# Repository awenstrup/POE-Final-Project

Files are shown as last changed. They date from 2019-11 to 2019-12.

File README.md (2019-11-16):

# POE-Final-Project

### Minimum Viable Product
Our MVP is to a build an intelligent, battery powered four wheel vehicle with remote data acquisition capabilities and sensor informed driving characteristics. Some stretch goals of ours are to include an intelligent drive algorithm with variable torque delivery for our wheels, self driving capabilities, aerodynamic features, video recording ability, and real time data plotting. We aim to prioritize robust, informed design and reliability. 

This project is a work in progress, with an estimated completion date in early December. Stay tuned for more updates.

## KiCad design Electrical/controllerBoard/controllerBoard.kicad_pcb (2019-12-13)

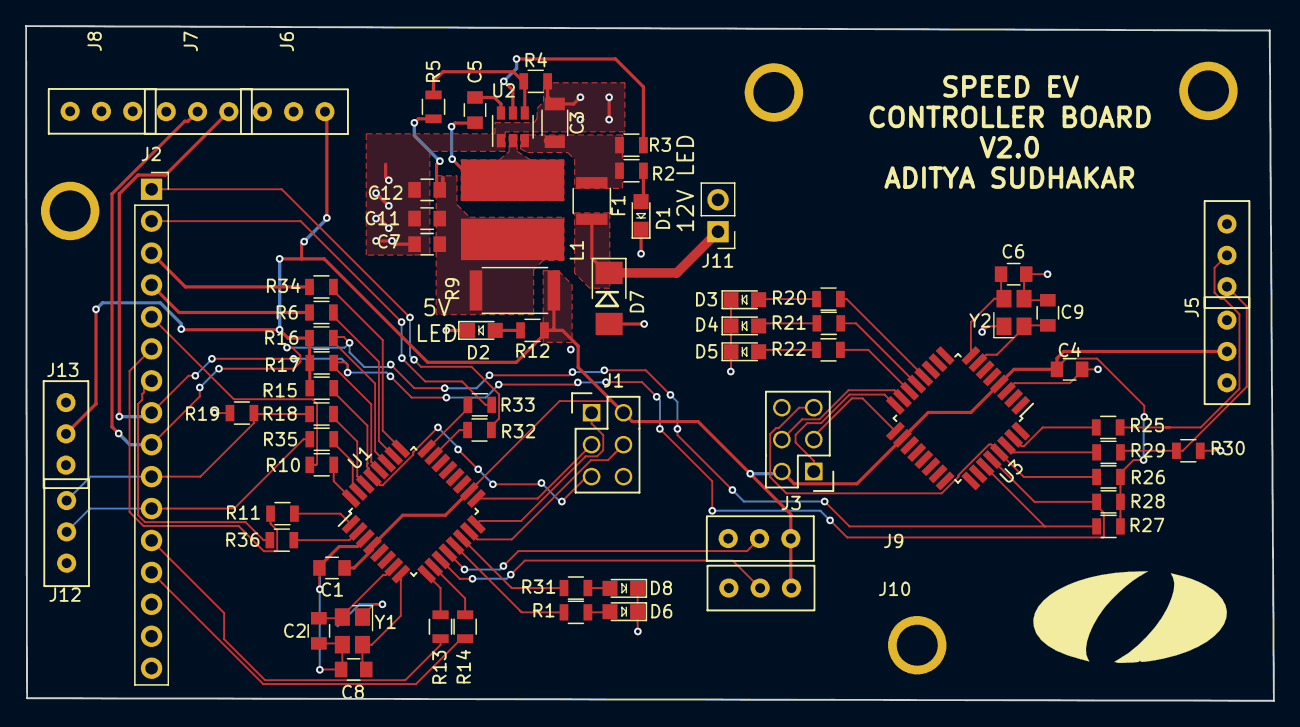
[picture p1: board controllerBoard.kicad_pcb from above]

Board: 2 copper layers, 99.3 x 53.7 mm, 71 parts (0 on the bottom side), 63 nets.

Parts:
C1, C4, C5, C12: C_0.1uF; C_0805_OEM
C2, C6, C8, C9: C_30pF; C_0805_OEM
C3: C_22uF; C_1206_OEM
C7: C_47uF; C_0805_OEM
C11: C_1uF; C_0805_OEM
D1, D2, D3, D4, D5, D6, D8: LED_0805; LED_0805_OEM
D7: D_Zener_18V; DO-214AA
F1: 500mA; Fuse_1210
J1, J3: CONN_02X03; Pin_Header_Straight_2x03
J2: 0.1in_Female_Socket_01x16; PinSocket_1x16_P2.54mm_Vertical
J4, J5, J6, J7, J8, J9, J10, J12, J13: CONN_01X03; MHSS1105
J11: CONN_01x02; PinHeader_1x02_P2.54mm_Vertical
L1: L_4.7uH; 4.7uH_Inductor_OEM
R1, R12, R20, R21, R22, R31: R_200; R_0805_OEM
R2: R_1k; R_0805_OEM
R3, R4: R_10k; R_0805_OEM
R5: R_51.1k; R_0805_OEM
R6, R10, R11, R13, R14, R25, R32, R33, R34, R35, R36: R_0; R_0805_OEM
R9: R_0_Jumper; R_2512_OEM
R15, R16, R17, R26, R27, R28: R_10K; R_0805_OEM
R18, R29: R_1K; R_0805_OEM
R19, R30: R_2.2K; R_0805_OEM
U1, U3: ATmega328P-AU; TQFP-32_7x7mm_P0.8mm
U2: TPS561201; SOT-23-6_OEM
Y1, Y2: Crystal_SMD; Crystal_SMD_FA238

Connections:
+9V: D7.1, F1.1, J11.1
/12V_Fused: C3.1, F1.2, R2.1, R3.1, U2.3
/IO1: J2.1, R32.1
/IO2: J2.2, R33.1
/IO3: J2.3, R34.1
/IO4: J2.4, R6.1
/IO5: J2.5, R10.1
/IO6: J2.6, R11.1
/IO7: J2.7, R36.1
/IO8: J2.12, R13.1
/IO9: J2.13, R14.1
/MISO: J1.1, U1.16
/MISO2: J3.1, U3.16
/MOSI: J1.4, U1.15
/MOSI2: J3.4, U3.15
/RESET: J1.5, R15.2, U1.29
/RESET2: J3.5, R26.2, U3.29
/RX: J2.10, J12.3, R18.1, R19.2
/RX2: J4.3, R29.1, R30.2
/SCK: J1.3, U1.17
/SCK2: J3.3, U3.17
/SCL: J2.8, J7.1, R17.2, R28.2, U1.28, U3.28
/SDA: J2.9, J7.2, R16.2, R27.2, U1.27, U3.27
/STEERING_SENSE: J10.2, U1.11
/THROTTLE_SENSE: J9.2, U1.12
/TX: J2.11, J12.2, R35.1
/TX2: J4.2, R25.1
/XTAL1: C2.1, U1.7, Y1.1
/XTAL2: C8.1, U1.8, Y1.3
/XTAL3: C9.1, U3.7, Y2.1
/XTAL4: C6.1, U3.8, Y2.3
GND: C1.2, C2.2, C3.2, C4.2, C6.2, C7.2, C8.2, C9.2, C11.2, C12.2, D1.1, D2.1, D3.1, D4.1, D5.1, D6.1, D7.2, D8.1, J1.6, J3.6, J5.1, J6.3, J9.3, J10.3, J11.2, J13.1, R4.2, R19.1, R30.1, U1.3, U2.1, U3.3, Y1.2, Y1.4, Y2.2, Y2.4
unnamed: C5.1, U2.6
unnamed: C5.2, L1.1, U2.2
unnamed: C7.1, C11.1, C12.1, L1.2, R5.2, R9.2
unnamed: D1.2, R2.2
unnamed: D2.2, R12.2
unnamed: D3.2, R20.1
unnamed: D4.2, R21.1
unnamed: D5.2, R22.1
unnamed: D6.2, R1.1
unnamed: D8.2, R31.1
unnamed: R1.2, U1.13
unnamed: R3.2, U2.5
unnamed: R4.1, R5.1, U2.4
unnamed: R6.2, U1.26
unnamed: R10.2, U1.32
unnamed: R11.2, U1.1
unnamed: R13.2, U1.9
unnamed: R14.2, U1.10
unnamed: R18.2, U1.30
unnamed: R20.2, U3.12
unnamed: R21.2, U3.13
unnamed: R22.2, U3.14
unnamed: R25.2, U3.31
unnamed: R29.2, U3.30
unnamed: R31.2, U1.14
unnamed: R32.2, U1.23
unnamed: R33.2, U1.24
unnamed: R34.2, U1.25
unnamed: R35.2, U1.31
unnamed: R36.2, U1.2
VCC: C1.1, C4.1, J1.2, J3.2, J5.2, J6.1, J9.1, J10.1, J13.2, R9.1, R12.1, R15.1, R16.1, R17.1, R26.1, R27.1, R28.1, U1.4, U1.18, U3.4, U3.18

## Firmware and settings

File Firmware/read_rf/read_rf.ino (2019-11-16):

//***********Include libraries***************
#include <Wire.h>
#include <Adafruit_MotorShield.h>
#include "utility/Adafruit_MS_PWMServoDriver.h"
#include <Servo.h>

//*************Define constants and global variables***************
#define throttlePin 5 //column 2 on reciever side; left stick up/down
#define steeringPin 6 //column 0 on reciever; right stick left/right

//Min and max pulse lengths from reciever, used for mapping
#define rawThrottleMin 1054
#define rawThrottleMax 1888
#define rawThrottleDeadZone 80

#define rawSteeringMin 1052
#define rawSteeringMax 1886

//Min and max values to write to DC motors through motor shield
#define throttleOutMin -255
#define throttleOutMax 255

//Min and max values to write to steering servo through motor shield
#define steeringOutMin 50
#define steeringOutMax 110

unsigned long timer = 0;
boolean go = false;

unsigned long rawThrottle = 0;
unsigned long rawSteering = 0;

//Stores the current state of the throttle and steering pins
boolean throtPinState = false;
boolean steerPinState = false;

//Set to true when a pin's state is changed
boolean throttleUpdate = false;
boolean steeringUpdate = false;

//Stores the time at which the pin went high
unsigned long steerStartTime;
unsigned long throtStartTime;

int throttleOut = 0;
int steeringOut = 80;

Adafruit_MotorShield AFMS = Adafruit_MotorShield(); 
Adafruit_DCMotor *drivingMotor1 = AFMS.getMotor(1); //motor 1 on shield
Adafruit_DCMotor *drivingMotor2 = AFMS.getMotor(2); //motor 2 on shield


Servo steering;
#define steeringServoPin 9

//************Setup*****************
void initTimer() { //addapted from https://www.instructables.com/id/Arduino-Timer-Interrupts/
  TCCR2A = 0;// set entire TCCR2A register to 0
  OCR2A = 255;// matches every 255 times
  // turn on CTC mode
  TCCR2A |= (1 << WGM21);
  // Set CS21 bit for 1024 prescaler
  TCCR2B |= 0b00000111;   
  // enable timer compare interrupt
  TIMSK2 |= (1 << OCIE2A);
}

void initPCINT() {
  //Enables interupts on shutdown sense pins
  PCICR |= 0b00000100; //enables PCINTs 16-23 
  PCMSK2 |= 0b01100000; //enables PCINT21 and PCINT22
}


//*************Interupts*************
ISR(TIMER2_COMPA_vect) {
    //count 800,000 times/second
    timer++;
    if (timer % 20 == 0) go = true;
}

ISR(PCINT2_vect) {
  boolean t1 = digitalRead(throttlePin);
  boolean t2 = digitalRead(steeringPin);
  throttleUpdate = (throtPinState != t1);
  steeringUpdate = (steerPinState != t2);
  throtPinState = t1;
  steerPinState = t2;
  digitalWrite(13, !digitalRead(13));
}



//************Helper functions******************
void readThrottle() { 
  //rudimentary implimentation used pulseIn arduino function
  //in future, either feed PWM though RC filter and analogRead, or use interupts
  //to read PWM more efficiently
  //rawThrottle = pulseIn(throttlePin, HIGH);

  if (throttleUpdate) {
    if (throtPinState) {
      throtStartTime = timer;
    }
    else {
      rawThrottle = timer - throtStartTime;
    }
    throttleUpdate = false;
  }
}

void readSteering() {
  //rudimentary implimentation used pulseIn arduino function
  //in future, either feed PWM though RC filter and analogRead, or use interupts
  //to read PWM more efficiently
  //rawSteering = pulseIn(steeringPin, HIGH);

  if (steeringUpdate) {
    if (steerPinState) {
      steerStartTime = timer;
    }
    else {
      rawSteering = timer - steerStartTime;
    }
    steeringUpdate = false;
  }
}

void mapThrottle() { //Converts raw throttle data to output
  //For week 1, return in range 0 to 255
  int rawThrottleMidpoint = (rawThrottleMax + rawThrottleMin) / 2;

  if (abs(rawThrottle - rawThrottleMidpoint) < rawThrottleDeadZone) rawThrottle = rawThrottleMidpoint;
  else if (rawThrottle < rawThrottleMin) rawThrottle = rawThrottleMin;
  else if (rawThrottle > rawThrottleMax) rawThrottle = rawThrottleMax;

  throttleOut = throttleOutMin + (rawThrottle - rawThrottleMin) * (throttleOutMax - throttleOutMin) / (rawThrottleMax - rawThrottleMin);
}

void mapSteering() { //Converts raw steering data to output
  //For week 1, return between 50 and 110
  if (rawSteering < rawSteeringMin) rawSteering = rawSteeringMin;
  else if (rawSteering > rawSteeringMax) rawSteering = rawSteeringMax;

  steeringOut = steeringOutMin + (rawSteering - rawSteeringMin) * (steeringOutMax - steeringOutMin) / (rawSteeringMax - rawSteeringMin);
}

//************Debugging*****************
void printThrottle() {
  char buff[32];
  sprintf(buff, "Raw throttle: %d", timer);
  Serial.println(buff);
}

//*************Setup and main loop**************
void setup() {
  //Set pins to receiver as input
  pinMode(throttlePin, INPUT);
  pinMode(steeringPin, INPUT);

  //Set pin 13 as debugging LED
  pinMode(9, OUTPUT);
  pinMode(13, OUTPUT);

  //Open serial port
  Serial.begin(9600);

  AFMS.begin();
  drivingMotor1->setSpeed(0);
  drivingMotor2->setSpeed(0);

  steering.attach(9);

  initTimer();
  initPCINT();
  sei();
}

void loop() {
  if (go) {
  go = false;
  //Read raw throttle and steering values from receiver
  readThrottle();
  readSteering();

  //Map raw throttle and steering data to output values
  mapThrottle();
  mapSteering();
  
  //Drive rear wheels
  drivingMotor1->setSpeed(throttleOut>0 ? throttleOut : -throttleOut);
  drivingMotor1->run(throttleOut>0 ? BACKWARD : FORWARD);
  
  drivingMotor2->setSpeed(throttleOut>0 ? throttleOut : -throttleOut);
  drivingMotor2->run(throttleOut>0 ? FORWARD : BACKWARD);

  //Update steering angle
  steering.write(steeringOut);

  digitalWrite(9, !digitalRead(9));
  }
}

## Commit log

2019-10-21 Added code to read and print PWM from RF reciever (have not set pins yet)
2019-10-22 Added structure for motor control to script; still not mapping raw reciever input to output
2019-10-24 Wrote code to drive sketch model car; have not tested yet; does not steer
2019-10-24 Working code for car rev0 (steering and forward movement via remote control)
2019-10-29 First draft of throttle code with reverse, not tested
    [read_rf.ino]
2019-10-29 Started adding interupts to replace pulseIn, not done yet
    [read_rf.ino]
2019-11-01 Finished first draft of of new code (using interupts instead of pulseIn); does not work
    [read_rf.ino]
2019-11-07 Continued work on interupts; timer working, PCINT not working as intended
    [read_rf.ino]
2019-11-15 adding website boiler plate
2019-11-16 -Adding Controller board KiCAD project files
    [controllerBoard-B.Cu.gbl, controllerBoard-B.Mask.gbs, controllerBoard-B.Paste.gbp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]
2019-11-17 pushing controller board files
    [controllerBoard.kicad_pcb]
2019-12-13 updating website and controller board
2019-12-13 updated controller board
    [controllerBoard-B_Cu.gbl, controllerBoard-B_Mask.gbs, controllerBoard-B_Paste.gbp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]
